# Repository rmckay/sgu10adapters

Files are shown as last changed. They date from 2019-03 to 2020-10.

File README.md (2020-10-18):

# sgu10adapters
3d part models to adapt SGU10 lamp fixtures to work with normal GU10 lamps instead of the overpriced Aurora AU-GUF4011/40 ones.

There are generally two parts, the SGU10 to GU10 adapter part and the 50mm to 63mm face ring adapter.

An instructional video [](https://youtu.be/2aEBEJwVzt0)

For the SGU10 to GU10 adapter, I recommend using the invertedsepco.stl design. All the rings are more or less the same.. the ringnarrow50.stl is the latest and slightly tighter but they all work fine.

A word of warning - do not print the electrical adapter part using carbon fiber as it is electrically conductive! Use non-conductive plastic filaments only.

# Assembly instructions:

  1) Cut GU10 socket wires to 4.5cm and skin off 4mm of insulation.
  2) Insert the bare ends of the wires into the hole in the side of the hexagonal supports inside the adapter.
  3) Insert the 10mm hex standoff into the hex holes in the bottom and push it in until it crimps the wires.
  4) Screw the 5mm M3 machine screw through the hole in the top of the hex support into the hex standoff inside.
  5) Screw the GU10 socket into the two round support pillars using the 12mm M3 plastic cutting screws.
  6) Screw the GU10 pins into the bottom of the hex standoff. (If you were unable to source proper GU10 pins, 12mm M3 socket cap allen bolts seem to work, screw them in about 5mm until they bottom out against the other 5mm M3 screw from step 4).

# Cost estimates:

| Description | Items per Pack | Needed per adapter | Cost per pack | Cost per adapter |
|---|---|---|---|---|
| | | | | |
| GU10 pins | 60 | 2 | £15.65 | £0.52 |
| GU10 socket | 20 | 1 | £8.46 | £0.42 |
| M3 12mm tail slot screws  | 20 | 2 | £1.20 | £0.13 |
| 10mm fem2fem hex standoff | 20 | 2 | £2.80 | £0.28 |
| M3 5mm machine screw | 20 | 2 | £1.79 | £0.18 |
| | | | | |
| Total | | | | £1.53 |

Add to that the cost of the 3d printing.. if you can get access to a 3d printer and just pay for the filament that'd be best.

If you can't get access to a 3d printer, the cheapest place I've found to make these is 3dlondon.org;

https://3dlondon.org/product/3d-printing-2/

invertedsepco.stl - £1.00 per unit in white PLA or £1.96 in PETG
ringnarrow50.stl - £1.00 per unit in white PLA or £1.43 in PETG

PETG should be somewhat higher quality.

Ordering from makeitquick.com;

invertedsepco.stl in white PC-ABS 80% fill £7.19 per unit
ringnarrow50.stl in white PC-ABS 20% fill  £3.16 per unit

Total cost of adapter: £11.88 per unit

If using the cheaper ENGINEERING PLASTIC for invertedsepco;

invertedsepco.stl in black EP 50% fill £4.77 per unit

Total cost then: £9.46 per unit

# Sourcing the parts

  * Two GU10 pins -- or maybe substitute another M3 machine screw 
    1. https://www.yoycart.com/Product/587235273486/Pure_copper_tinned_bile_machine_stereo_D
    2. https://item.taobao.com/item.htm?spm=a21wu.10013406.0.0.6d2f7bbdUvWl7A&id=548601464465
    3. https://item.taobao.com/item.htm?spm=2013.1.20141002.6.76592e6fjjatwZ
    4. https://www.1688.com/huo/detail-557699757054.html?spm=a262i4.9164788.zhaohuo-list-offerlist.46.4ea37870irYewZ
    5. https://www.ebay.co.uk/itm/221306240232 (an alternative to actual GU10 pins is to use a 12mm M3 socket cap allen bolt.. it's not the right thing, but it does fit in the socket and they're cheap and easy to get anywhere.

  * A GU10 socket 
    1. https://www.amazon.co.uk/gp/product/B00K2TJ4I8/
  * Two standard M3 5mm machine screws
    1. https://www.ebay.co.uk/itm/M3-3mm-A2-STAINLESS-STEEL-POZI-PAN-HEAD-MACHINE-SCREWS-POZIDRIVE-BOLTS-UK/111304543360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
  * Two 12mm M3 self tapping screws
    1. https://www.ebay.co.uk/itm/M1-M3-Phillips-Pan-Head-Self-Tapping-Screw-Cross-Recessed-Nickel-Plated-/274437065032
  * Two hex standoffs 10mm, I prefer nickel ones -- the unplated brass colored hexes are slightly narrower and don't fit quite so well.
    1. https://www.ebay.co.uk/itm/Hex-Female-M3-Nickel-Plated-Pillar-PCB-Hexagonal-Standoff-Studs-Support/263855977592
    2. https://www.ebay.co.uk/itm/Nickel-Plated-Female-Female-M3-Thread-Pillar-PCB-Spacer-Studs-Standoff-Hex/192784823415
    3. https://www.ebay.co.uk/itm/Nickel-M3-Female-Hexagonal-Pillar-Hex-Spacer-Threaded-Standoff/153679541113

# Images

newold
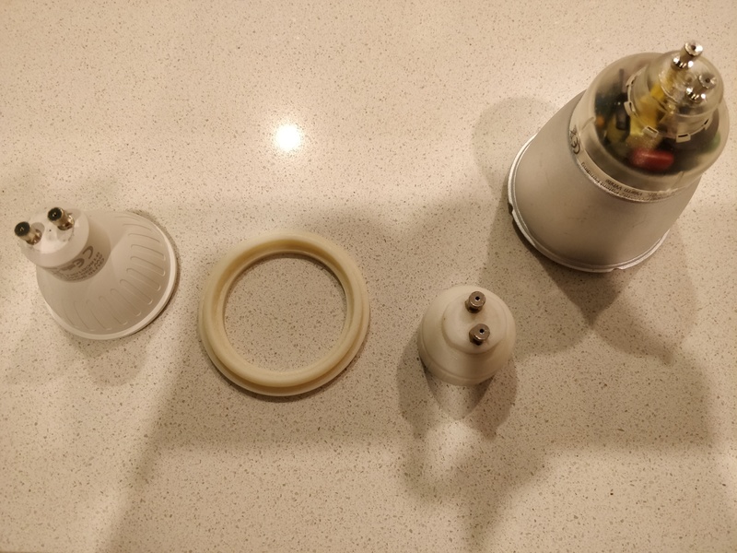
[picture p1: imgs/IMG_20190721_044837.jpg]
unstacked


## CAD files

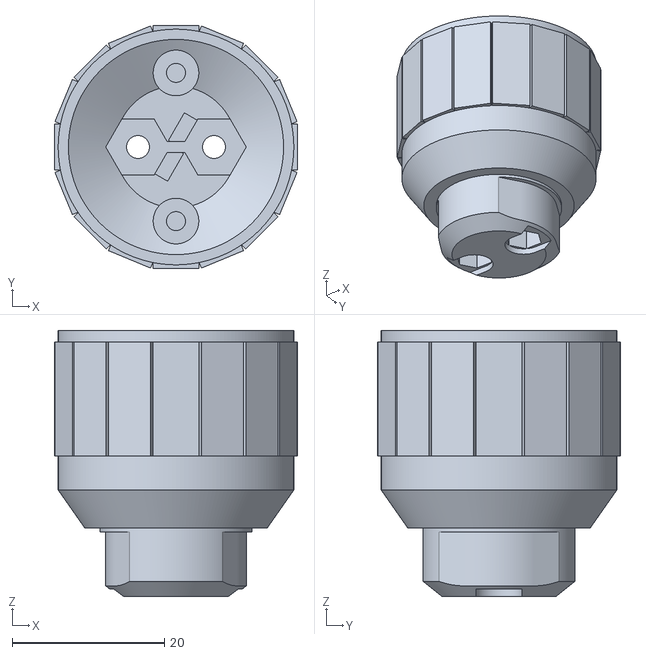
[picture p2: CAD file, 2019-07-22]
stl/invertedsepco.stl
32.0 x 32.0 x 35.0

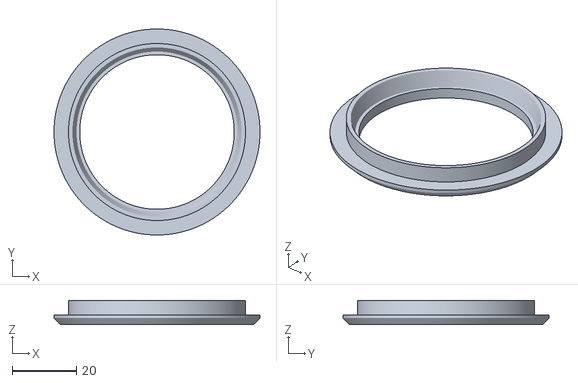
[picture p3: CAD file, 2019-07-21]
stl/sgu10ring.stl
64.0 x 64.0 x 7.50

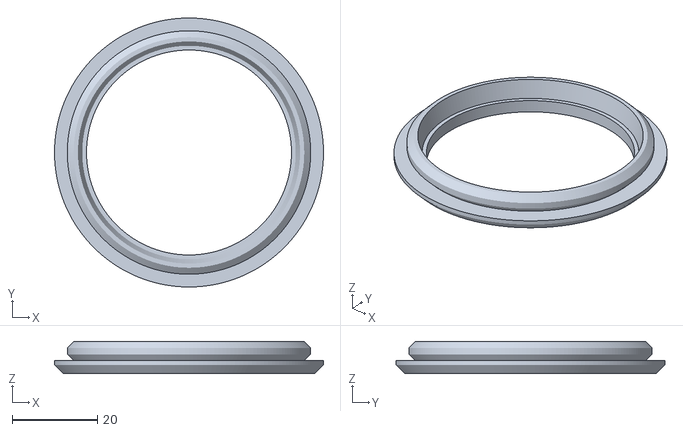
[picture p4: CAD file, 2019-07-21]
stl/ringnarrow50.stl
63.0 x 63.0 x 7.50

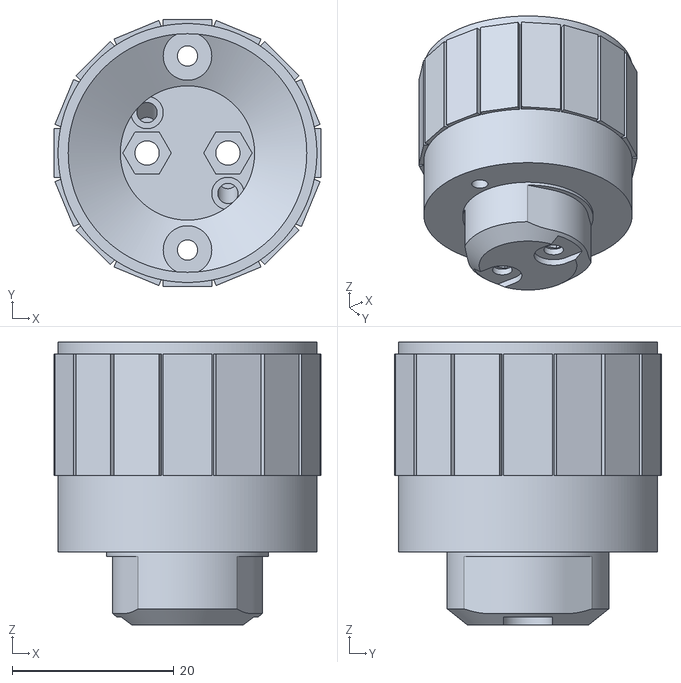
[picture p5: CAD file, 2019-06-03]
stl/sgu10sqclmp.stl
33.0 x 33.0 x 35.0

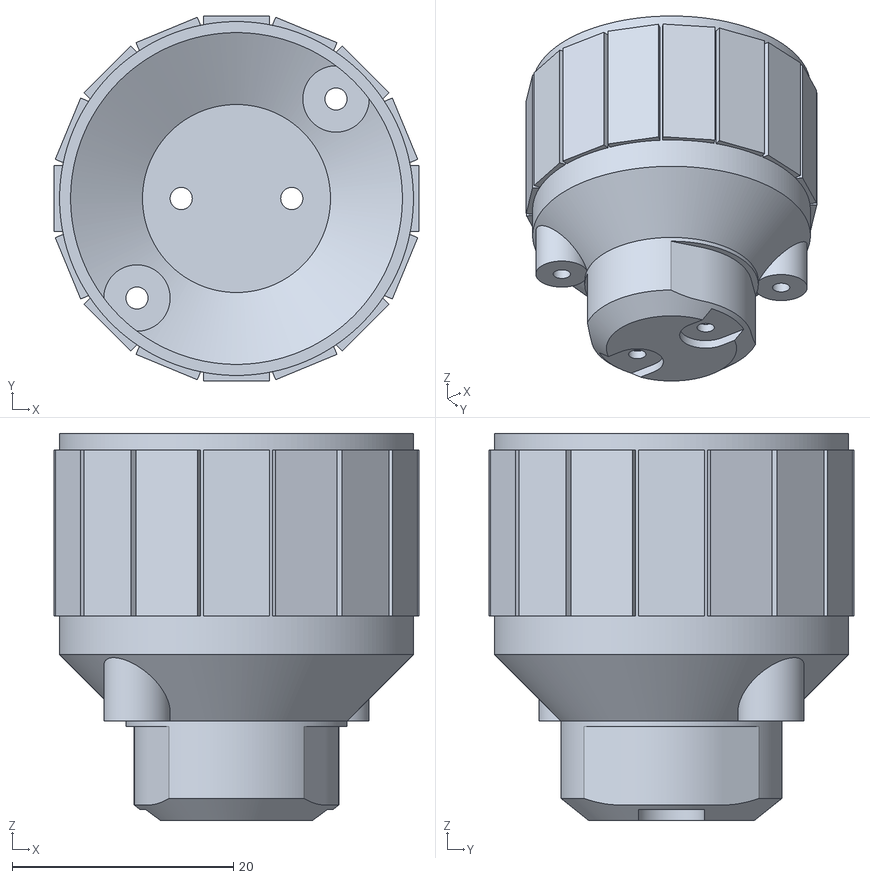
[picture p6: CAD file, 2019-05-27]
stl/sgu10ramped.stl
33.0 x 33.0 x 35.0

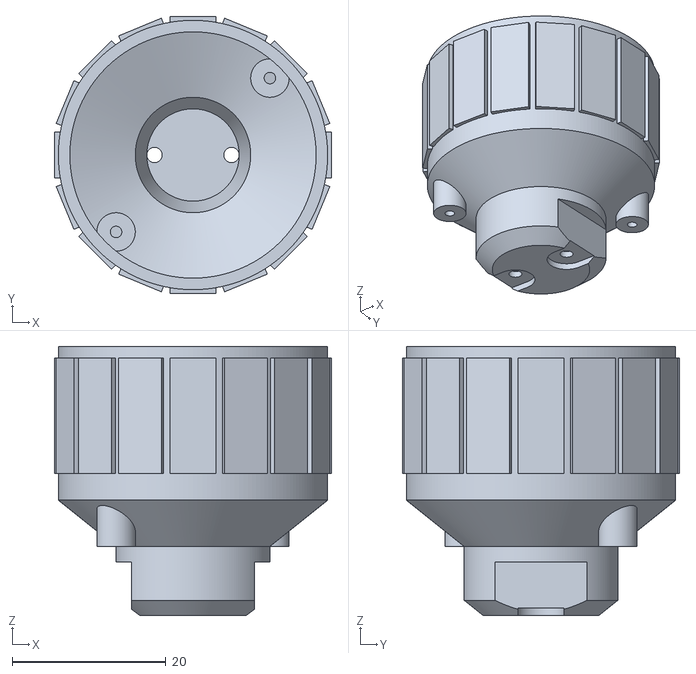
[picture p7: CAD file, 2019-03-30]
stl/gu10lampholdersh.stl
36.0 x 36.0 x 35.0

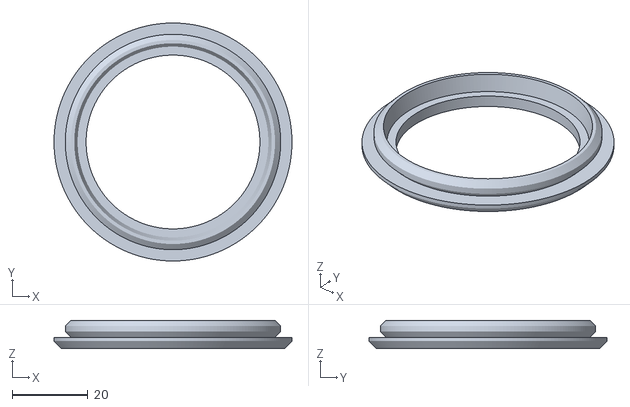
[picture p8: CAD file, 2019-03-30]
stl/ring.stl
63.0 x 63.0 x 7.50

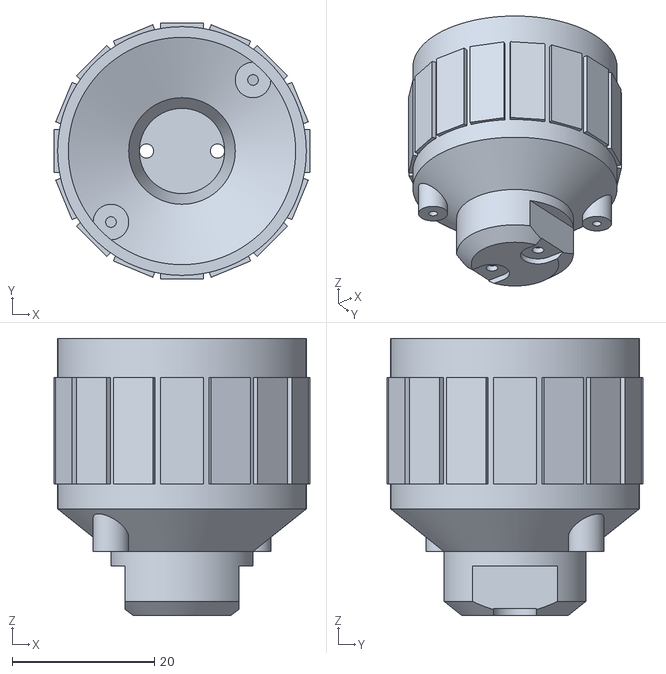
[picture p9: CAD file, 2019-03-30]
stl/gu10lampholder.stl
36.0 x 36.0 x 39.0

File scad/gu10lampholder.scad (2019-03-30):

// TODO
// pin holes squared off [x]
// screw tubes set to right height
// screw tubes truncated


    bottom_circle_width = 15;
    bottom_circle_height = 2;
    
    plug_width = 20;
    plug_height = 7;
    grip_height = 26;

difference() {
   // for (i=[0:10:360]) 
 // rotate([0,0,i]) translate([0,0,h_ext+1.5*100/2-0.5]) cube([2,1.2*100,1.5*100],center=true);
    
 //    rotate_extrude($fn = 180)
 //      translate([0.5, 1, 0]) 
 //           circle(r = 1);
       
    

    

    
    rotate_extrude($fn = 180)
        translate([0,0,0]) 
           polygon( points=[[0,0], // middle
                    [bottom_circle_width/2,0], // diameter of bottom circle
                    [plug_width/2,bottom_circle_height], // diameter of top of socket
                    [plug_width/2,plug_height+bottom_circle_height], // diameter of top of socket bezel
                    [35/2,plug_height+bottom_circle_height+6], // diameter of plug neck at top
                    [35/2,plug_height+grip_height+bottom_circle_height], // outter diameter of grip
                    [32/2,plug_height+grip_height+bottom_circle_height], // inner diameter of grip
                    [32/2,plug_height+bottom_circle_height+7], // inner diameter of plug neck at top
                    [bottom_circle_width/2,plug_height+bottom_circle_height+3], // inner diameter at socket bezel at top
                    [(bottom_circle_width/2)-1.5,bottom_circle_height],
                    [0,bottom_circle_height],  // inner diameter of socket bezel at bottom
                    [0,bottom_circle_height], // thickness of bottom Y side 
                    [0,0]] ); // back to start
                    
                    
     // make holes for pins
     translate([-5,0,0]) 
        cylinder(d=2,h=3,center=false,$fn=180);
        
     translate([5,0,0])
        cylinder(d=2,h=3,center=false,$fn=180);
        
         // cutouts for pin thrust pad
     translate([-5,0,0]) 
        cylinder(d=6,h=1,center=false,$fn=360);
      //  cube([15,15,8],center=false);
        
     translate([5,0,0])
        cylinder(d=6,h=1,center=false,$fn=360);
        
      
    // square off pin holes
     translate([5,-3,0])
        cube([15,6,1],center=false);
        
     translate([-20,-3,0])
        cube([15,6,1],center=false);

        
     // crucial SGU10 slots
     
     translate([9,0,3])
        cube([2,15,8],center=true);
        
     translate([-9,0,3])
        cube([2,15,8],center=true);
        

        
}

    h_canal=30; 
    h_ext=3;
    d_lamp=20;

 for (i=[0:22.5:360]) 
  rotate([0,0,i]) translate([18,0,26]) cube([2,6,15],center=true);
  //translate([0,0,h_canal/2+h_ext-h_canal]) difference(){
  //      cylinder(d=d_lamp,h=h_canal,center=false,$fn=180);
  //      cylinder(d=d_lamp-2,h=h_canal+1,center=false,$fn=180);
 // }
 
    
          // make screw holders
     translate([-10,-10,plug_height+bottom_circle_height]) difference() {
        cylinder(d=5,h=10,center=false,$fn=180);
        cylinder(d=1.5,h=10,center=false,$fn=180);
     }
        
     translate([10,10,plug_height+bottom_circle_height]) difference() {
        cylinder(d=5,h=10,center=false,$fn=180);
        cylinder(d=1.5,h=10,center=false,$fn=180);
     }
       
 
 

 
  

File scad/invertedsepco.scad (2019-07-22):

// TODO
// pin holes squared off [x]
// screw tubes set to right height
// screw tubes truncated


    bottom_circle_width = 15;
    bottom_circle_height = 2;
    
    plug_width = 20;
    plug_height = 7;
    grip_height = 26;
    
    plug_outter_width = 31;
    plug_inner_width = 28.3;
    
    // screw holes
    
    outw = 6;
    inw = 2.5;
    offset = (18 / 2)-(inw /2);
    
    // height of hex spacer
    hexheight = 9;

difference() {
   // for (i=[0:10:360]) 
 // rotate([0,0,i]) translate([0,0,h_ext+1.5*100/2-0.5]) cube([2,1.2*100,1.5*100],center=true);
    
 //    rotate_extrude($fn = 180)
 //      translate([0.5, 1, 0]) 
 //           circle(r = 1);
       
    

    

    
    rotate_extrude($fn = 180)
        translate([0,0,0]) 
           polygon( points=[[0,0], // middle
                    [bottom_circle_width/2,0], // diameter of bottom circle
                    [plug_width/2,bottom_circle_height], // diameter of top of socket
                    [plug_width/2,plug_height+bottom_circle_height], // diameter of top of socket bezel
                    [(plug_outter_width/2)-3.5,plug_height+bottom_circle_height], // diameter of plug neck at top
                    [(plug_outter_width/2),plug_height+bottom_circle_height+5], // diameter of plug neck at top
                    [plug_outter_width/2,plug_height+grip_height+bottom_circle_height], // outter diameter of grip
                    [plug_inner_width/2,plug_height+grip_height+bottom_circle_height], // inner diameter of grip
                    [plug_inner_width/2,plug_height+bottom_circle_height+7], // inner diameter of plug neck at top
                    [bottom_circle_width/2+0.5,plug_height+bottom_circle_height+3], // inner diameter at socket bezel at top
                    [(bottom_circle_width/2)+0.5,bottom_circle_height],
                    [0,bottom_circle_height],  // inner diameter of socket bezel at bottom
                    [0,bottom_circle_height], // thickness of bottom Y side 
                    [0,0]] ); // back to start
                    
                    
     // make holes for pins
     translate([-5,0,0]) 
        cylinder(d=6,h=3,center=false,$fn=6);
        
     translate([5,0,0])
        //cylinder(d=3,h=3,center=false,$fn=180);
        cylinder(d=6,h=3,center=false,$fn=6);
        
         // cutouts for pin thrust pad
     translate([-5,0,0]) 
        cylinder(d=6,h=1,center=false,$fn=360);
      //  cube([15,15,8],center=false);
        
     translate([5,0,0])
        cylinder(d=6,h=1,center=false,$fn=360);
        
      
    // square off pin holes
     translate([5,-3,0])
        cube([15,6,1],center=false);
        
     translate([-20,-3,0])
        cube([15,6,1],center=false);

        
     // crucial SGU10 slots
     for (i=[-30:1:30]) 
        rotate([0,0,i]) translate([10,0,3]) cube([1.5,15,11],center=true);   
     
     for (i=[-30+180:1:30+180]) 
        rotate([0,0,i]) translate([10,0,3]) cube([1.5,15,11],center=true);   
        
     
      translate([0,offset+2,plug_height+bottom_circle_height+2]) difference() {
          cylinder(d=inw,h=10-2,center=false,$fn=180);
      }
      
      translate([0,-offset-2,plug_height+bottom_circle_height+2]) difference() {
           cylinder(d=inw,h=10-2,center=false,$fn=180);
      }
    
    
    // cut to examine thicknesses  
    //   translate([10,0,0]) difference() {
    //    cube([5,5,10], center=true);
   // }
      
}

    h_canal=30; 
    h_ext=3;
    d_lamp=20;

 for (i=[0:22.5:360]) 
  rotate([0,0,i]) translate([plug_outter_width/2,0,26]) cube([1,6,15],center=true);
  //translate([0,0,h_canal/2+h_ext-h_canal]) difference(){
  //      cylinder(d=d_lamp,h=h_canal,center=false,$fn=180);
  //      cylinder(d=d_lamp-2,h=h_canal+1,center=false,$fn=180);
 // }
 
 
          // make screw holders
      
     translate([0,-offset-2,plug_height+bottom_circle_height+2]) difference() {
        cylinder(d=outw,h=10-2,center=false,$fn=180);
        cylinder(d=inw,h=10,center=false,$fn=180);
     }
        
     translate([0,offset+2,plug_height+bottom_circle_height+2]) difference() {
        cylinder(d=outw,h=10-2,center=false,$fn=180);
        cylinder(d=inw,h=10,center=false,$fn=180);
     }
     
    difference() {             
     translate([-5,0,2]) 
        cylinder(d=8.5,h=hexheight+2,center=false,$fn=6);
     
     translate([-5,0,2]) 
        cylinder(d=6,h=hexheight,center=false,$fn=6);
        
     translate([-5,0,hexheight+1])
        cylinder(d=3,h=3,center=false,$fn=180);
        
     // side holes for wire
     translate([-5,0,hexheight])
        rotate([30,90,0])
        cylinder(d=3,h=5,center=false,$fn=180);
     
    

        
}

// wire guide into hole block
 translate([-3.7,-3,7.7]) 
    rotate([30,90,0])
        cube([4.7,4.2,3]);

     // side holes for wire
//    translate([-5,0,10])
///        rotate([30,90,0])
//        cylinder(d=2.5,h=5,center=false,$fn=180);   

difference() {
     translate([5,0,2]) 
        cylinder(d=8.5,h=hexheight+2,center=false,$fn=6);
        
        
     translate([5,0,2])
        cylinder(d=6,h=hexheight,center=false,$fn=6);
    
    translate([5,0,hexheight+1])
        cylinder(d=3,h=3,center=false,$fn=180);
    
    
     // side holes for wire
     translate([5,0,hexheight])
        rotate([-30,-90,0])
        cylinder(d=3,h=5,center=false,$fn=180);   
 
     }
     
     
     // wire guide into hole block
 translate([3.7,3,7.7]) 
    rotate([210,90,0])
        cube([4.7,4.2,3]);
     
     // separator slot
 translate([-1.5,0.75,13])
     rotate([90,90,0])
     cube([10,3,1.5]);
     
     
     // make wire guide
     
     
  //   translate([0,-3,0]) difference() {
  //      cylinder(d=outw,h=10,center=false,$fn=180);
  //      rotate([3,3,0]) cylinder(d=inw,h=10,center=false,$fn=180);
   //  }
        
  //   translate([0,3,0]) difference() {
   //     cylinder(d=outw,h=10,center=false,$fn=180);
   //     cylinder(d=inw,h=10,center=false,$fn=180);
  //   }
  

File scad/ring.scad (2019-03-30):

//  Diseño de portalámparas SÓLO para lámparas LED GU10/GU5.3
//  IMPORTANTE:
//      *  USAR BAJO SU PROPIA RESPONSABILIDAD
//      *  NO UTILIZAR CON BOMBILLAS HALÓGENAS, RIESGO DE INCENDIO DEL PLÁSTICO
//      *  UTILIZAR PLÁSTICOS QUE AGUANTEN CIERTA TEMPERATURA COMO ABS, PETG
//      *  EL PLA SE REBLANCECE/DERRITE A TEMPERATURA "BAJA"

//  Por David Sáinz
//  30 de Junio de 2016

// Diseño de portalámpara LED diámetro taladro 54mm para LED GU10/GU5.3 de 50mm de diámetro
// alojamiento de portalámparas
d_hueco=54;  //diámetro donde va alojado el portalámpara, en este caso para un hueco de 55mm, con algo de holgura.
h_hueco=0;     //altura del cilindro portalámpara/grosor falso techo
//  medidas exteriores
d_ext=63; //diámetro exterior del embellecedor
h_ext=3; //grosor del embellecedor exterior
chaflan=2;   //chaflán en mm del embellecedor exterior
d_inf=46; //diámetro inferior de sujección de lámpara;
//
d_lamp=50.5; //diámetro donde va alojada la lámpara GU10/GU5.3, de 50mm
// canales de refrigeración
ang_canal=0; // ángulo de separación entre canales de refrigeración inferior
a_canal=0;   // anchura de canales de refrigeración
h_canal=0;   //  altura de canales de refrigeración
// sujección portalámparas a alojamiento
ang_garra=30;  // ángulo de separación entre garras de sujección
a_garra=1.5;   // distancia en mm para el agarre del portalámparas en alojamiento
h_garra=1.5;   // altura de chaflán inferior y superior de la garra


difference()
{
// cuerpo del portalámparas
    
    translate([0, 0, 0])
       rotate_extrude($fn = 180)
            polygon( points=[[d_inf/2,0],[d_ext/2-chaflan,0],[d_ext/2,chaflan],[d_ext/2,h_ext],[d_hueco/2,h_ext],[d_hueco/2,h_ext+h_hueco],[d_hueco/2+a_garra,h_ext+h_hueco+h_garra],[d_hueco/2+a_garra,h_ext+h_hueco+2*h_garra],[d_hueco/2,h_ext+h_hueco+3*h_garra],[(d_hueco+d_lamp)/4,h_ext+h_hueco+3*h_garra],[d_lamp/2,h_ext],[d_inf/2,h_ext]] );
    
// ranuras ventilacion lámpara
    
 
  
// cortes cilindro 
  
  for (i=[0:ang_garra:360]) 
  rotate([0,0,i]) translate([0,0,h_ext+1.5*h_hueco/2-0.5]) cube([2,1.2*d_ext,1.5*h_hueco],center=true);

}

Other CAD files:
stl/sgu10rampedthicker.stl
stl/ringnarrow.stl
scad/gu10lampholdersh.scad
scad/ringnarrow.scad
scad/ringnarrow50.scad
scad/sgu10clamp.scad
scad/sgu10ramped.scad
scad/sgu10rampedthicker.scad
scad/sgu10ring.scad
scad/sgu10sqclmp.scad

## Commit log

2019-03-30 Adding scad and stl files
    [gu10lampholder.scad, gu10lampholder.stl, gu10lampholdersh.scad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]
2019-05-27 added rounded notch
    [awen.dxf, sgu10ramped.scad, sgu10ramped.stl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]
2019-06-03 added new design
    [sgu10clamp.scad, sgu10sqclmp.scad, sgu10sqclmp.stl]
2019-06-03 moved to scad dir
    [sgu10sqclmp.scad]
2019-06-03 added to dir
    [sgu10sqclmp.scad]
2019-07-21 invert design can now accommodate normal bolts instead of special gu10 binding posts as contacts
    [awen.dxf]
2019-07-21 added inverted design to accommodate normal m3 bolts as well as gu10 binding posts as contact pins
    [invertedsepco.scad, invertedsepco.stl, ringnarrow50.scad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]
2019-07-21 basic assembly instructions
2019-07-21 tried to add stl
2019-07-21 added new slightly larger ring design
    [sgu10ring.scad, sgu10ring.stl]
2019-07-22 larger cable ramp and tighter inner width
    [invertedsepco.scad, invertedsepco.stl]
2019-07-23 added allen bolt instructions
2020-04-10 added video corrected bolt size info
2020-10-18 updated urls and fixed a couple of mistakes.
